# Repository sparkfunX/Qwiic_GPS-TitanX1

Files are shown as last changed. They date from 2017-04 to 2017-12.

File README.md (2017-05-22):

Qwiic GPS - Titan X1
========================================

Qwiic GPS with Titan X1

[*SPX-14312*](https://www.sparkfun.com/products/14312)

A breakboard board for the Titan X1 GPS module including an external antenna connection and RTC backup.

The [Qwiic system](http://www.sparkfun.com/qwiic) enables fast and solderless connection between popular platforms and various sensors and actuators. You can read more about the Qwiic system [here](http://www.sparkfun.com/qwiic). 

License Information
-------------------

This product is _**open source**_!

Please review the LICENSE.md file for license information.

If you have any questions or concerns on licensing, please contact techsupport@sparkfun.com.

Distributed as-is; no warranty is given.

- Your friends at SparkFun.

_<COLLABORATION CREDIT>_

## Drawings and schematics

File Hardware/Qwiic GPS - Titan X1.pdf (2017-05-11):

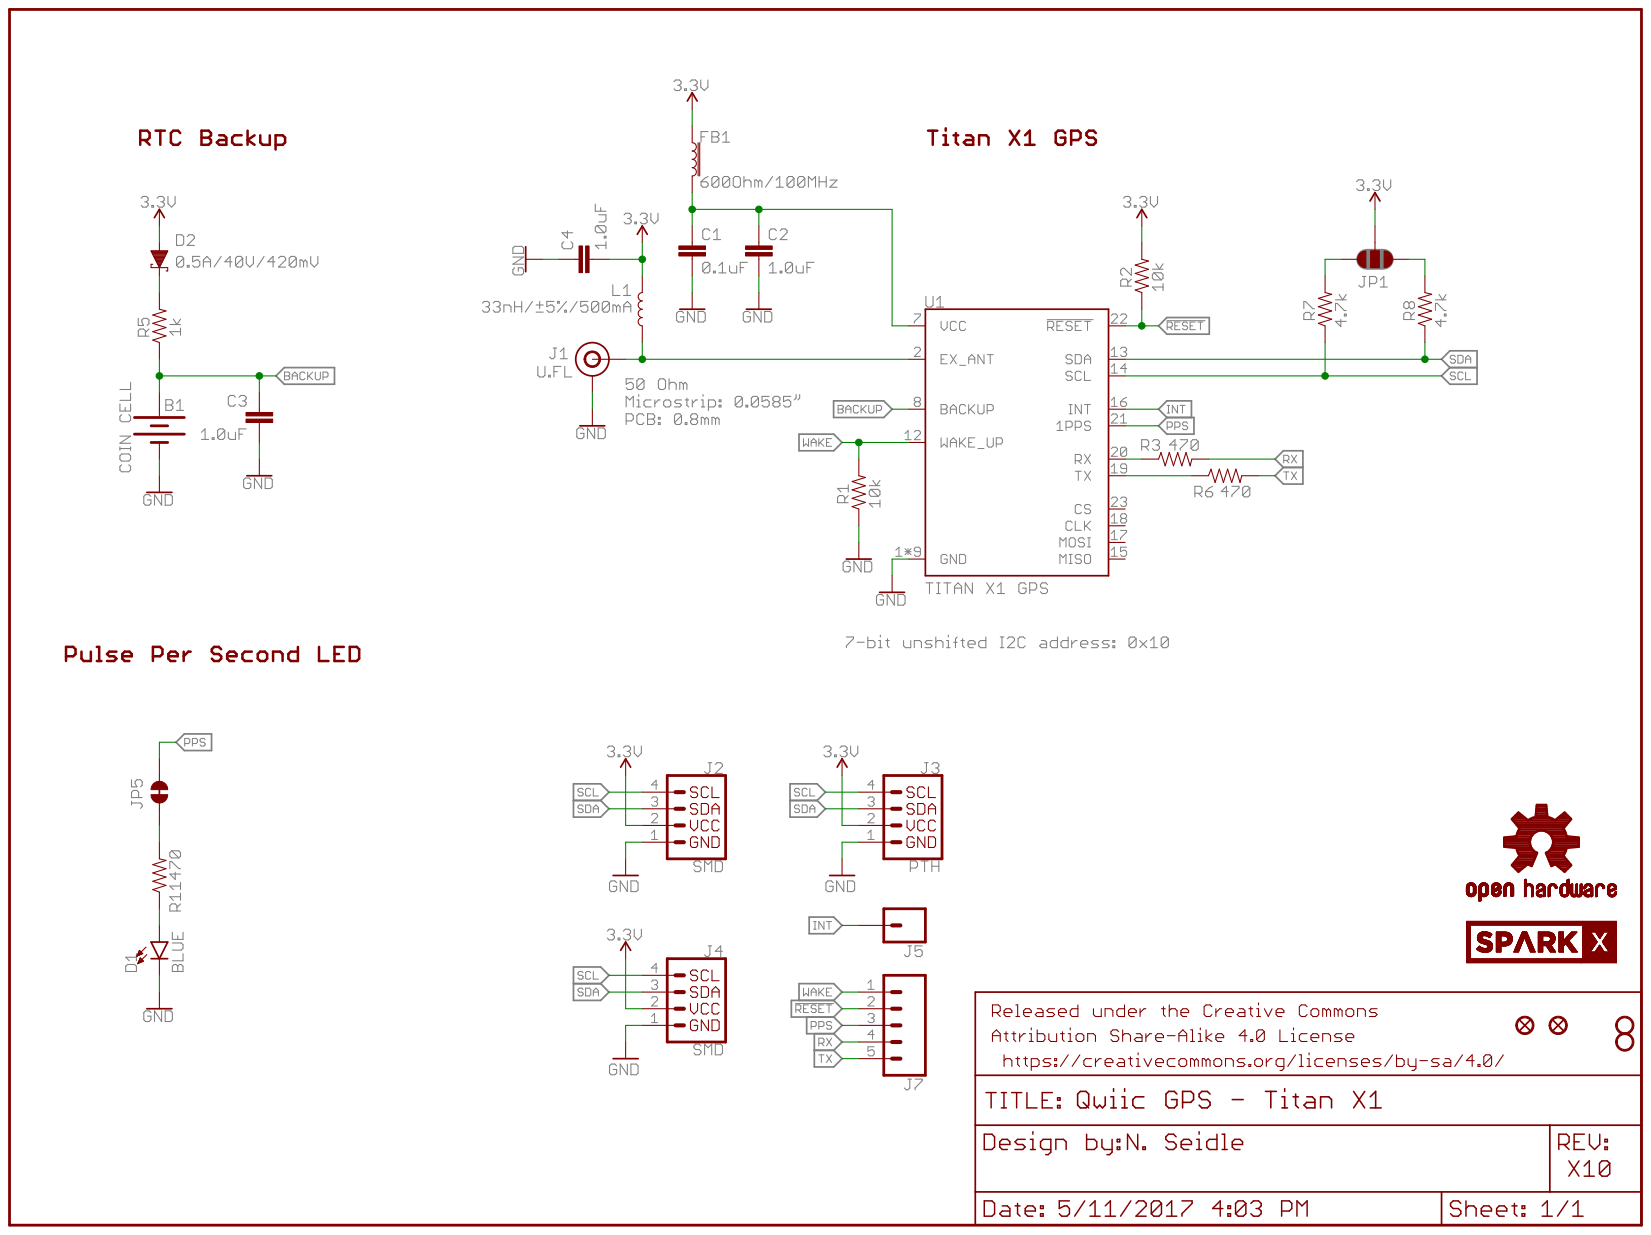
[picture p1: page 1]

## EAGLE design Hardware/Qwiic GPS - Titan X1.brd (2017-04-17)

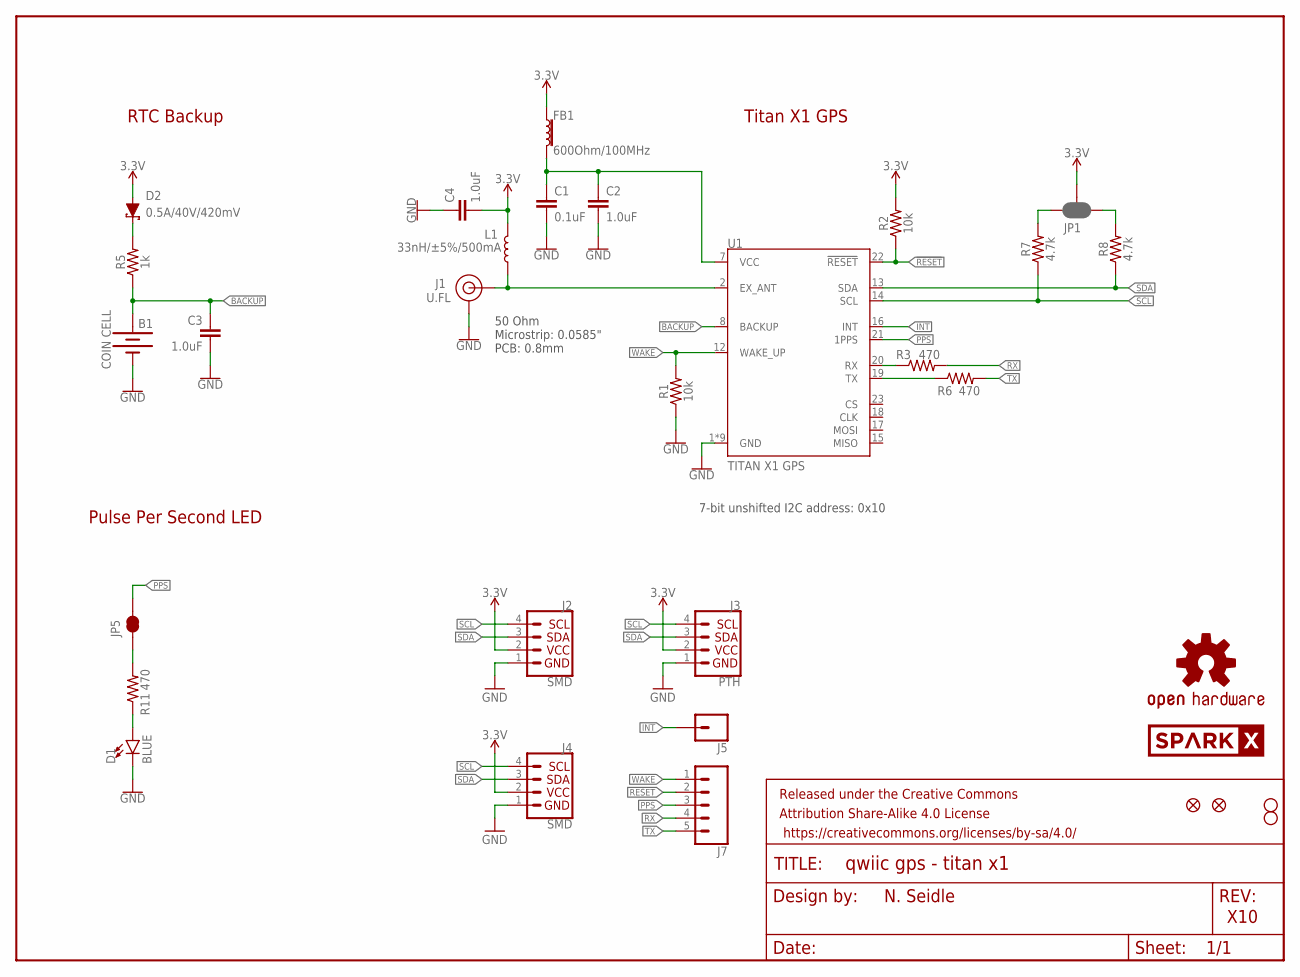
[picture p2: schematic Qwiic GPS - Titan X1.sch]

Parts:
B1: COIN CELL; 6.8MM_COIN_CELL
C1: 0.1uF; 0603
C2, C3, C4: 1.0uF; 0603
D1: BLUE; LED-0603
D2: 0.5A/40V/420mV; SOD-323
FB1: 600Ohm/100MHz; 0603
FRAME1: FRAME-LETTER; CREATIVE_COMMONS
J1: U.FL
J2, J4: SMD; 1X04_1MM_RA
J3: PTH; 1X04_NO_SILK
J5: CONN_01PTH_NO_SILK_YES_STOP; 1X01_NO_SILK
J7: CONN_05NO_SILK; 1X05_NO_SILK
JP1: JUMPER-SMT_3_2-NC_PASTE_SILK; SMT-JUMPER_3_2-NC_PASTE_SILK
JP2, JP6: FIDUCIALUFIDUCIAL; MICRO-FIDUCIAL
JP3, JP4: STAND-OFF
JP5: JUMPER-SMT_2_NC_TRACE_NO-SILK; SMT-JUMPER_2_NC_TRACE_NO-SILK
L1: 33nH/±5%/500mA; 0603
LOGO1: OSHW-LOGOMINI; OSHW-LOGO-MINI
R1, R2: 10k; 0603
R3, R6, R11: 470; 0603
R5: 1k; 0603
R7, R8: 4.7k; 0603
U1: TITAN X1 GPS; TITAN_X1_GPS
U$1: SPARKX-LOGO5; SPARKX-LARGE

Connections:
3.3V: C4.2, D2.A, FB1.1, J2.2 (VCC), J3.2 (VCC), J4.2 (VCC), JP1.2, L1.2, R2.2
!RESET: J7.2, R2.1, U1.22 (!RESET)
BACKUP: B1.+, C3.1, R5.1, U1.8 (BACKUP)
EXT_ANT: J1.FEED (SIGNAL), L1.1, U1.2 (EX_ANT)
GND: B1.-, C1.2, C2.2, C3.2, C4.1, D1.C, J1.1 (GND), J1.2 (GND), J2.1 (GND), J3.1 (GND), J4.1 (GND), R1.1, U1.1 (GND), U1.3 (GND), U1.4 (GND), U1.5 (GND), U1.6 (GND), U1.9 (GND), U1.10 (GND), U1.11 (GND), U1.24 (GND)
INT: J5.1, U1.16 (INT)
unnamed: D1.A, R11.1
unnamed: JP5.1, R11.2
unnamed: JP1.1, R8.2
unnamed: D2.C, R5.2
unnamed: JP1.3, R7.2
PPS: J7.3, JP5.2, U1.21 (1PPS)
RX: J7.4, R3.2
RXLV: R3.1, U1.20 (RX)
SCL: J2.4 (SCL), J3.4 (SCL), J4.4 (SCL), R7.1, U1.14 (SCL)
SDA: J2.3 (SDA), J3.3 (SDA), J4.3 (SDA), R8.1, U1.13 (SDA)
TX: J7.5, R6.2
TXLV: R6.1, U1.19 (TX)
VCC_FILTERED: C1.1, C2.1, FB1.2, U1.7 (VCC)
WAKE: J7.1, R1.2, U1.12 (WAKE_UP)

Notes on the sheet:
N. Seidle
X10
7-bit unshifted I2C address: 0x10
Titan X1 GPS
RTC Backup
Pulse Per Second LED
50 Ohm Microstrip: 0.0585" PCB: 0.8mm

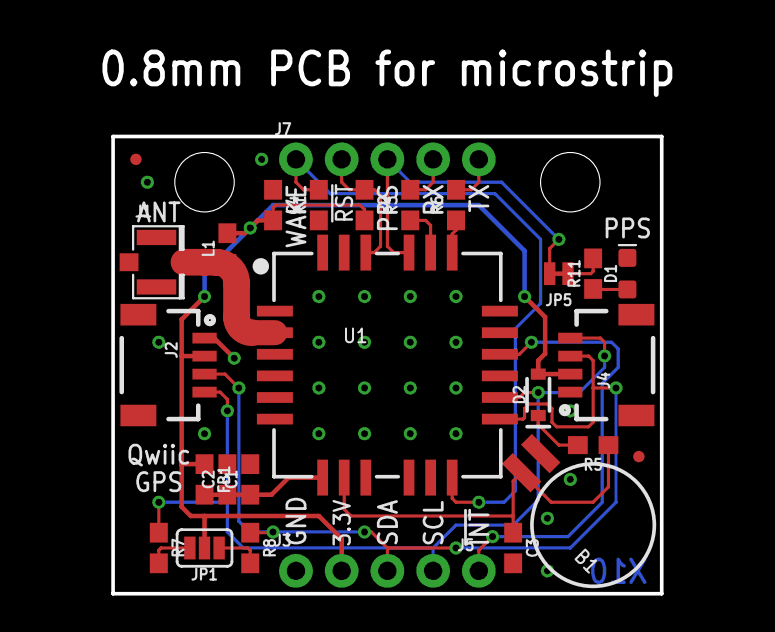
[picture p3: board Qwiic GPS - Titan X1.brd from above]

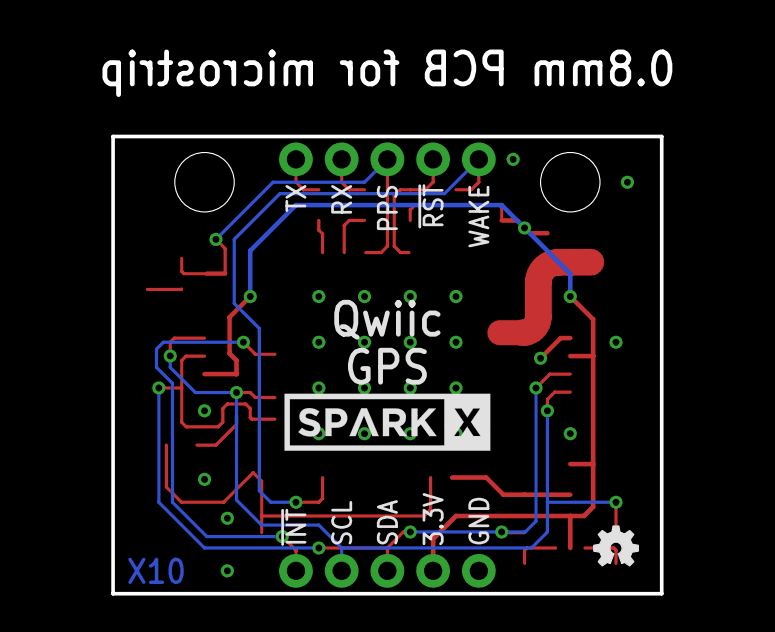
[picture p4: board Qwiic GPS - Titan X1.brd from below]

Board: 2 copper layers, 30.5 x 25.4 mm, 33 parts (2 on the bottom side), 20 nets.

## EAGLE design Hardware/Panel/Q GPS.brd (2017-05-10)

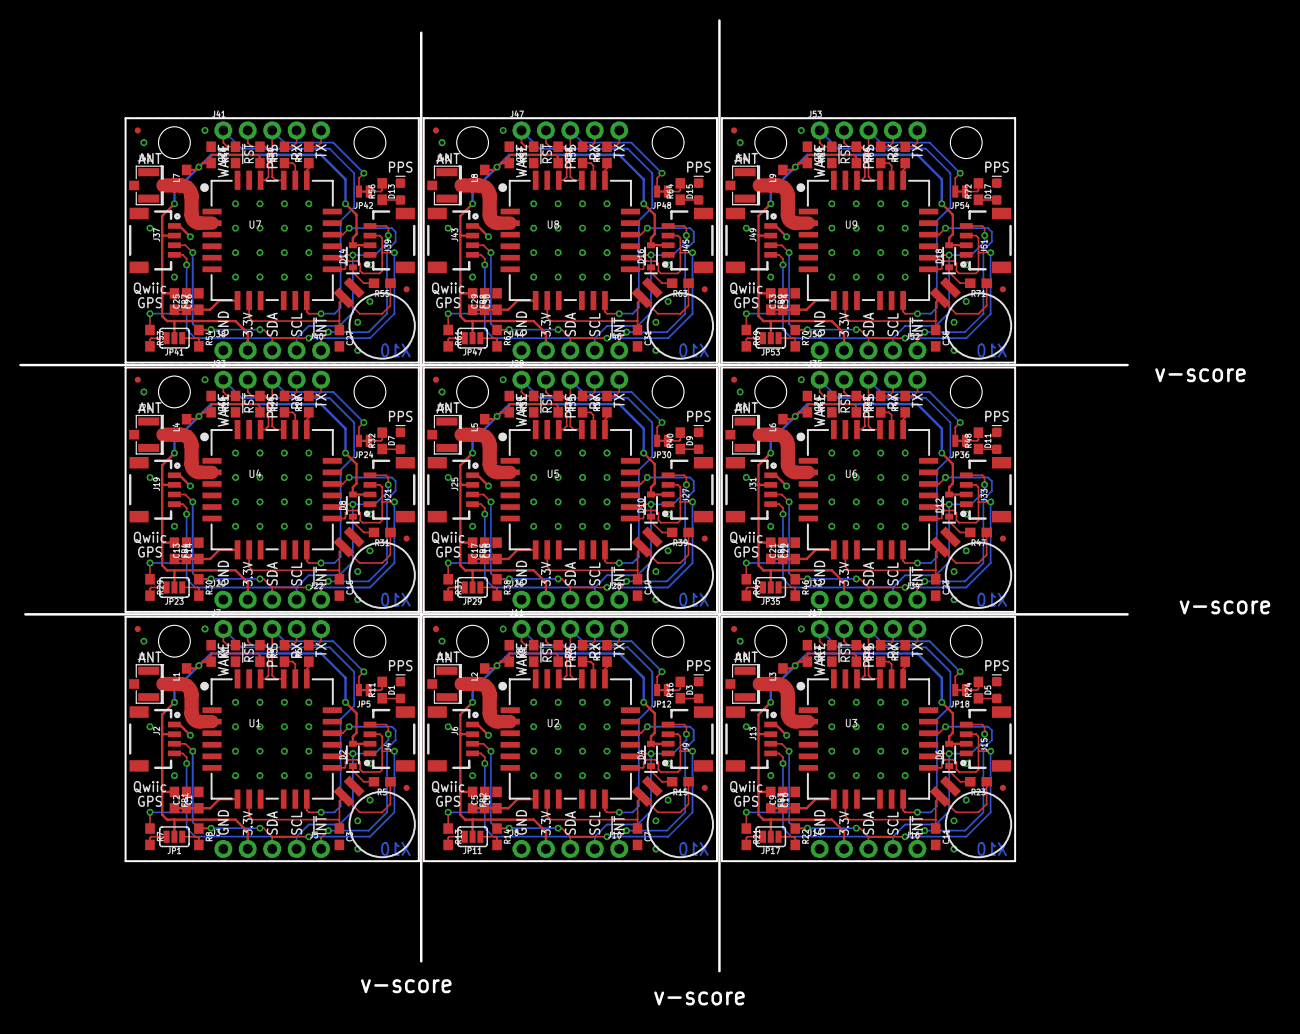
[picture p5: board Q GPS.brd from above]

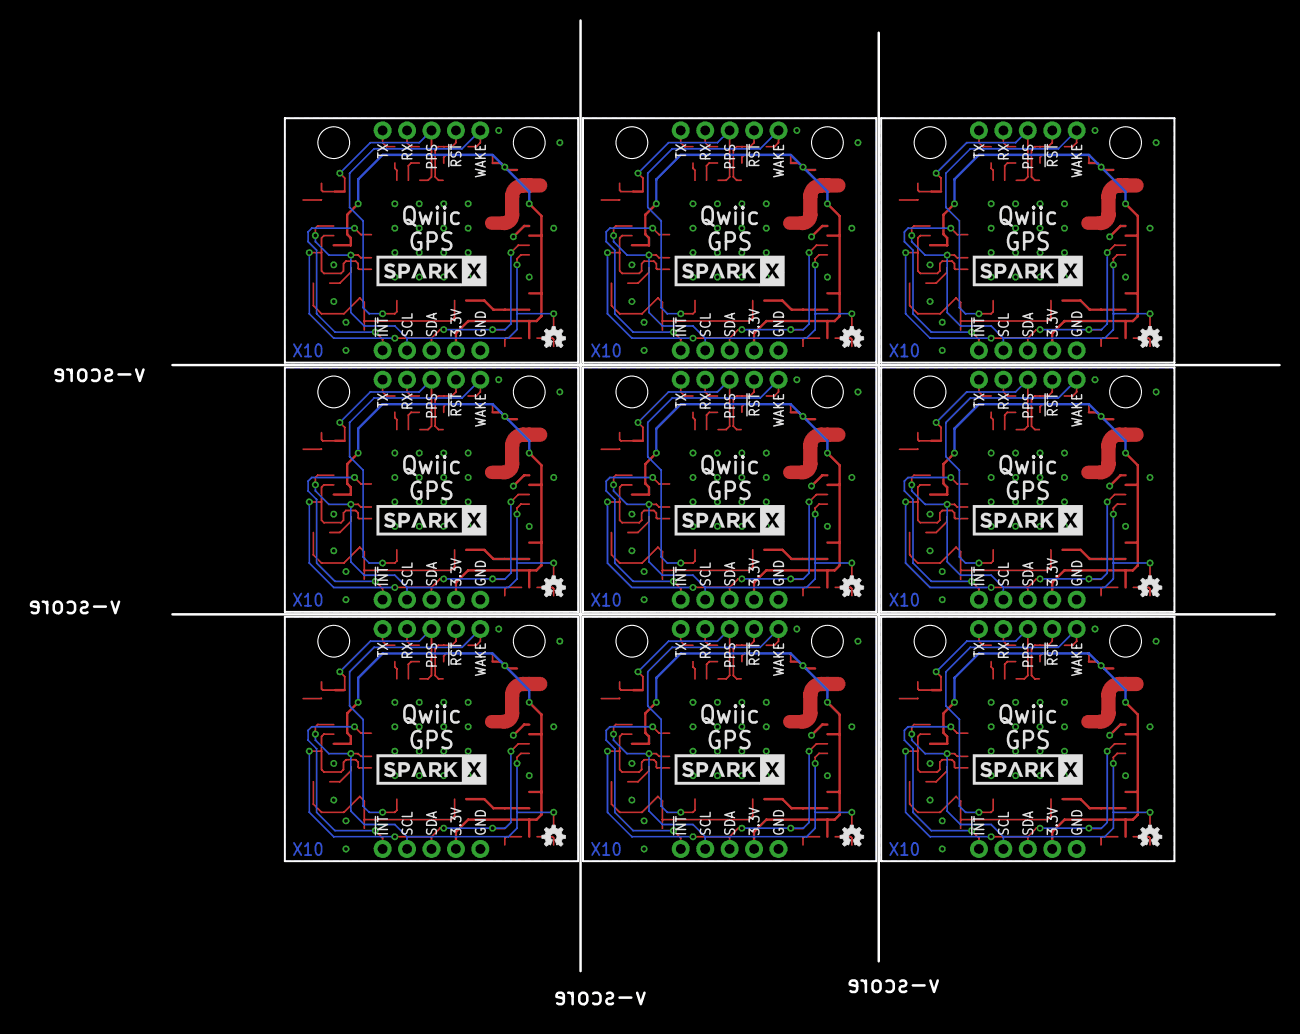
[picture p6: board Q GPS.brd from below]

Board: 2 copper layers, 115.1 x 98.8 mm, 288 parts (18 on the bottom side), 180 nets.

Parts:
B1, B2, B3, B4, B5, B6, B7, B8, B9: COIN CELL; 6.8MM_COIN_CELL
C1, C6, C10, C14, C18, C22, C26, C30, C34: 0.1uF; 0603
C2, C3, C4, C5, C7, C8, C9, C11, C12, C13, C15, C16, C17, C19, C20, C21, C23, C24, C25, C27, C28, C29, C31, C32, C33, C35, C36: 1.0uF; 0603
D1, D3, D5, D7, D9, D11, D13, D15, D17: BLUE; LED-0603
D2, D4, D6, D8, D10, D12, D14, D16, D18: 0.5A/40V/420mV; SOD-323
FB1, FB2, FB3, FB4, FB5, FB6, FB7, FB8, FB9: 600Ohm/100MHz; 0603
J1, J12, J18, J24, J30, J36, J42, J48, J54: U.FL
J2, J4, J6, J9, J13, J15, J19, J21, J25, J27, J31, J33, J37, J39, J43, J45, J49, J51: SMD; 1X04_1MM_RA
J3, J8, J14, J20, J26, J32, J38, J44, J50: PTH; 1X04_NO_SILK
J5, J10, J16, J22, J28, J34, J40, J46, J52: 1X01_NO_SILK
J7, J11, J17, J23, J29, J35, J41, J47, J53: 1X05_NO_SILK
JP1, JP11, JP17, JP23, JP29, JP35, JP41, JP47, JP53: SMT-JUMPER_3_2-NC_PASTE_SILK
JP2, JP6, JP9, JP10, JP15, JP16, JP21, JP22, JP27, JP28, JP33, JP34, JP39, JP40, JP45, JP46, JP51, JP52: FIDUCIALUFIDUCIAL; MICRO-FIDUCIAL
JP3, JP4, JP7, JP8, JP13, JP14, JP19, JP20, JP25, JP26, JP31, JP32, JP37, JP38, JP43, JP44, JP49, JP50: STAND-OFF
JP5, JP12, JP18, JP24, JP30, JP36, JP42, JP48, JP54: SMT-JUMPER_2_NC_TRACE_NO-SILK
L1, L2, L3, L4, L5, L6, L7, L8, L9: 33nH/±5%/500mA; 0603
LOGO1, LOGO2, LOGO3, LOGO4, LOGO5, LOGO6, LOGO7, LOGO8, LOGO9: OSHW-LOGOMINI; OSHW-LOGO-MINI
R1, R2, R4, R9, R17, R18, R25, R26, R33, R34, R41, R42, R49, R50, R57, R58, R65, R66: 10k; 0603
R3, R6, R10, R11, R12, R16, R19, R20, R24, R27, R28, R32, R35, R36, R40, R43, R44, R48, R51, R52, R56, R59, R60, R64, R67, R68, R72: 470; 0603
R5, R15, R23, R31, R39, R47, R55, R63, R71: 1k; 0603
R7, R8, R13, R14, R21, R22, R29, R30, R37, R38, R45, R46, R53, R54, R61, R62, R69, R70: 4.7k; 0603
U1, U2, U3, U4, U5, U6, U7, U8, U9: TITAN X1 GPS; TITAN_X1_GPS
U$1, U$2, U$3, U$4, U$5, U$6, U$7, U$8, U$9: SPARKX-LOGO5; SPARKX-LARGE

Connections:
1PPS: J7.3, JP5.2, U1.21
1PPS1: J11.3, JP12.2, U2.21
1PPS2: J17.3, JP18.2, U3.21
1PPS3: J23.3, JP24.2, U4.21
1PPS4: J29.3, JP30.2, U5.21
1PPS5: J35.3, JP36.2, U6.21
1PPS6: J41.3, JP42.2, U7.21
1PPS7: J47.3, JP48.2, U8.21
1PPS8: J53.3, JP54.2, U9.21
3.3V: C4.2, D2.A, FB1.1, J2.2, J3.2, J4.2, JP1.2, L1.2, R2.2
3.3V1: C8.2, D4.A, FB2.1, J6.2, J8.2, J9.2, JP11.2, L2.2, R9.2
3.3V2: C12.2, D6.A, FB3.1, J13.2, J14.2, J15.2, JP17.2, L3.2, R18.2
3.3V3: C16.2, D8.A, FB4.1, J19.2, J20.2, J21.2, JP23.2, L4.2, R26.2
3.3V4: C20.2, D10.A, FB5.1, J25.2, J26.2, J27.2, JP29.2, L5.2, R34.2
3.3V5: C24.2, D12.A, FB6.1, J31.2, J32.2, J33.2, JP35.2, L6.2, R42.2
3.3V6: C28.2, D14.A, FB7.1, J37.2, J38.2, J39.2, JP41.2, L7.2, R50.2
3.3V7: C32.2, D16.A, FB8.1, J43.2, J44.2, J45.2, JP47.2, L8.2, R58.2
3.3V8: C36.2, D18.A, FB9.1, J49.2, J50.2, J51.2, JP53.2, L9.2, R66.2
!RESET: J7.2, R2.1, U1.22
!RESET1: J11.2, R9.1, U2.22
!RESET2: J17.2, R18.1, U3.22
!RESET3: J23.2, R26.1, U4.22
!RESET4: J29.2, R34.1, U5.22
!RESET5: J35.2, R42.1, U6.22
!RESET6: J41.2, R50.1, U7.22
!RESET7: J47.2, R58.1, U8.22
!RESET8: J53.2, R66.1, U9.22
BACKUP: B1.+, C3.1, R5.1, U1.8
BACKUP1: B2.+, C7.1, R15.1, U2.8
BACKUP2: B3.+, C11.1, R23.1, U3.8
BACKUP3: B4.+, C15.1, R31.1, U4.8
BACKUP4: B5.+, C19.1, R39.1, U5.8
BACKUP5: B6.+, C23.1, R47.1, U6.8
BACKUP6: B7.+, C27.1, R55.1, U7.8
BACKUP7: B8.+, C31.1, R63.1, U8.8
BACKUP8: B9.+, C35.1, R71.1, U9.8
EXT_ANT: J1.FEED, L1.1, U1.2
EXT_ANT1: J12.FEED, L2.1, U2.2
EXT_ANT2: J18.FEED, L3.1, U3.2
EXT_ANT3: J24.FEED, L4.1, U4.2
EXT_ANT4: J30.FEED, L5.1, U5.2
EXT_ANT5: J36.FEED, L6.1, U6.2
EXT_ANT6: J42.FEED, L7.1, U7.2
EXT_ANT7: J48.FEED, L8.1, U8.2
EXT_ANT8: J54.FEED, L9.1, U9.2
GND: B1.-, C1.2, C2.2, C3.2, C4.1, D1.C, J1.1, J1.2, J2.1, J3.1, J4.1, R1.1, U1.1, U1.3, U1.4, U1.5, U1.6, U1.9, U1.10, U1.11, U1.24
GND1: B2.-, C5.2, C6.2, C7.2, C8.1, D3.C, J6.1, J8.1, J9.1, J12.1, J12.2, R4.1, U2.1, U2.3, U2.4, U2.5, U2.6, U2.9, U2.10, U2.11, U2.24
GND2: B3.-, C9.2, C10.2, C11.2, C12.1, D5.C, J13.1, J14.1, J15.1, J18.1, J18.2, R17.1, U3.1, U3.3, U3.4, U3.5, U3.6, U3.9, U3.10, U3.11, U3.24
GND3: B4.-, C13.2, C14.2, C15.2, C16.1, D7.C, J19.1, J20.1, J21.1, J24.1, J24.2, R25.1, U4.1, U4.3, U4.4, U4.5, U4.6, U4.9, U4.10, U4.11, U4.24
GND4: B5.-, C17.2, C18.2, C19.2, C20.1, D9.C, J25.1, J26.1, J27.1, J30.1, J30.2, R33.1, U5.1, U5.3, U5.4, U5.5, U5.6, U5.9, U5.10, U5.11, U5.24
GND5: B6.-, C21.2, C22.2, C23.2, C24.1, D11.C, J31.1, J32.1, J33.1, J36.1, J36.2, R41.1, U6.1, U6.3, U6.4, U6.5, U6.6, U6.9, U6.10, U6.11, U6.24
GND6: B7.-, C25.2, C26.2, C27.2, C28.1, D13.C, J37.1, J38.1, J39.1, J42.1, J42.2, R49.1, U7.1, U7.3, U7.4, U7.5, U7.6, U7.9, U7.10, U7.11, U7.24
GND7: B8.-, C29.2, C30.2, C31.2, C32.1, D15.C, J43.1, J44.1, J45.1, J48.1, J48.2, R57.1, U8.1, U8.3, U8.4, U8.5, U8.6, U8.9, U8.10, U8.11, U8.24
GND8: B9.-, C33.2, C34.2, C35.2, C36.1, D17.C, J49.1, J50.1, J51.1, J54.1, J54.2, R65.1, U9.1, U9.3, U9.4, U9.5, U9.6, U9.9, U9.10, U9.11, U9.24
INT: J5.1, U1.16
INT1: J10.1, U2.16
INT2: J16.1, U3.16
INT3: J22.1, U4.16
INT4: J28.1, U5.16
INT5: J34.1, U6.16
INT6: J40.1, U7.16
INT7: J46.1, U8.16
INT8: J52.1, U9.16
unnamed: JP11.1, R14.2
unnamed: D1.A, R11.1
unnamed: JP11.3, R13.2
unnamed: JP5.1, R11.2
unnamed: JP1.1, R8.2
unnamed: D2.C, R5.2
unnamed: D3.A, R16.1
unnamed: JP1.3, R7.2
unnamed: JP12.1, R16.2
unnamed: D4.C, R15.2
unnamed: JP17.1, R22.2
unnamed: JP17.3, R21.2
unnamed: D5.A, R24.1
unnamed: JP18.1, R24.2
unnamed: D6.C, R23.2
unnamed: JP23.1, R30.2
unnamed: JP23.3, R29.2
unnamed: D7.A, R32.1
unnamed: JP24.1, R32.2
unnamed: D8.C, R31.2
unnamed: JP29.1, R38.2
unnamed: JP29.3, R37.2
unnamed: D9.A, R40.1
unnamed: JP30.1, R40.2
unnamed: D10.C, R39.2
unnamed: JP35.1, R46.2
unnamed: JP35.3, R45.2
unnamed: D11.A, R48.1
unnamed: JP36.1, R48.2
unnamed: D12.C, R47.2
unnamed: JP41.1, R54.2
unnamed: JP41.3, R53.2
unnamed: D13.A, R56.1
unnamed: JP42.1, R56.2
unnamed: D14.C, R55.2
unnamed: JP47.1, R62.2
unnamed: JP47.3, R61.2
unnamed: D15.A, R64.1
unnamed: JP48.1, R64.2
unnamed: D16.C, R63.2
unnamed: JP53.1, R70.2
unnamed: JP53.3, R69.2
unnamed: D17.A, R72.1
unnamed: JP54.1, R72.2
unnamed: D18.C, R71.2
RX: J7.4, R3.2
RX1: J11.4, R10.2
RX2: J17.4, R19.2
RX3: J23.4, R27.2
RX4: J29.4, R35.2
RX5: J35.4, R43.2
RX6: J41.4, R51.2
RX7: J47.4, R59.2
RX8: J53.4, R67.2
RXLV: R3.1, U1.20
RXLV1: R10.1, U2.20
RXLV2: R19.1, U3.20
RXLV3: R27.1, U4.20
RXLV4: R35.1, U5.20
RXLV5: R43.1, U6.20
RXLV6: R51.1, U7.20
RXLV7: R59.1, U8.20
RXLV8: R67.1, U9.20
SCL: J2.4, J3.4, J4.4, R7.1, U1.14
SCL1: J6.4, J8.4, J9.4, R13.1, U2.14
SCL2: J13.4, J14.4, J15.4, R21.1, U3.14
SCL3: J19.4, J20.4, J21.4, R29.1, U4.14
SCL4: J25.4, J26.4, J27.4, R37.1, U5.14
SCL5: J31.4, J32.4, J33.4, R45.1, U6.14
SCL6: J37.4, J38.4, J39.4, R53.1, U7.14
SCL7: J43.4, J44.4, J45.4, R61.1, U8.14
SCL8: J49.4, J50.4, J51.4, R69.1, U9.14
SDA: J2.3, J3.3, J4.3, R8.1, U1.13
SDA1: J6.3, J8.3, J9.3, R14.1, U2.13
SDA2: J13.3, J14.3, J15.3, R22.1, U3.13
SDA3: J19.3, J20.3, J21.3, R30.1, U4.13
SDA4: J25.3, J26.3, J27.3, R38.1, U5.13
SDA5: J31.3, J32.3, J33.3, R46.1, U6.13
SDA6: J37.3, J38.3, J39.3, R54.1, U7.13
SDA7: J43.3, J44.3, J45.3, R62.1, U8.13
SDA8: J49.3, J50.3, J51.3, R70.1, U9.13
TX: J7.5, R6.2
TX1: J11.5, R12.2
TX2: J17.5, R20.2
TX3: J23.5, R28.2
TX4: J29.5, R36.2
TX5: J35.5, R44.2
TX6: J41.5, R52.2
TX7: J47.5, R60.2
TX8: J53.5, R68.2
TXLV: R6.1, U1.19
TXLV1: R12.1, U2.19
TXLV2: R20.1, U3.19
TXLV3: R28.1, U4.19
TXLV4: R36.1, U5.19
TXLV5: R44.1, U6.19
TXLV6: R52.1, U7.19
TXLV7: R60.1, U8.19
TXLV8: R68.1, U9.19
VCC_FILTERED: C1.1, C2.1, FB1.2, U1.7
VCC_FILTERED1: C5.1, C6.1, FB2.2, U2.7
VCC_FILTERED2: C9.1, C10.1, FB3.2, U3.7
VCC_FILTERED3: C13.1, C14.1, FB4.2, U4.7
VCC_FILTERED4: C17.1, C18.1, FB5.2, U5.7
VCC_FILTERED5: C21.1, C22.1, FB6.2, U6.7
VCC_FILTERED6: C25.1, C26.1, FB7.2, U7.7
VCC_FILTERED7: C29.1, C30.1, FB8.2, U8.7
VCC_FILTERED8: C33.1, C34.1, FB9.2, U9.7
WAKE: J7.1, R1.2, U1.12
WAKE1: J11.1, R4.2, U2.12
WAKE2: J17.1, R17.2, U3.12
WAKE3: J23.1, R25.2, U4.12
WAKE4: J29.1, R33.2, U5.12
WAKE5: J35.1, R41.2, U6.12
WAKE6: J41.1, R49.2, U7.12
WAKE7: J47.1, R57.2, U8.12
WAKE8: J53.1, R65.2, U9.12

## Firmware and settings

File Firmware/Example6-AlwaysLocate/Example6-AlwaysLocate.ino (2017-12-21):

/*
  Configure GPS module for low power operate
  By: Nathan Seidle
  SparkFun Electronics
  Date: April 12th, 2017
  License: This code is public domain but you buy me a beer if you use this and we meet someday (Beerware license).

  This example shows how to configure the module including:
    AlwaysLocate (packet # 225)

  For more information see the MTK NMEA Packet datasheet.

  Note that these settings are stored in battery backed memory and will be retained for
  approximately 16 days without power.

  Hardware Connections:
  Attach a Qwiic shield to your RedBoard or Uno.
  Plug the Qwiic sensor into any port.
  Serial.print it out at 115200 baud to serial monitor.
*/

#include <SparkFun_I2C_GPS_Arduino_Library.h> //Use Library Manager or download here: https://github.com/sparkfun/SparkFun_I2C_GPS_Arduino_Library
I2CGPS myI2CGPS; //Hook object to the library

#include <TinyGPS++.h> //From: https://github.com/mikalhart/TinyGPSPlus
TinyGPSPlus gps; //Declare gps object

//The following tells the TinyGPS library to scan for the PMTK001 sentence
//This sentence is the response to a configure command from the user
//Field 1 is the packet number, 2 indicates if configuration was successful
TinyGPSCustom configureCmd(gps, "PMTK001", 1); //Packet number
TinyGPSCustom configureFlag(gps, "PMTK001", 2); //Success/fail flag

String configString;

boolean debug = false; //Keeps track of the enable/disable of debug printing within the GPS lib

void setup()
{
  Serial.begin(115200);
  Serial.println("GPS Configuration Example");

  if (myI2CGPS.begin() == false)
  {
    Serial.println("Module failed to respond. Please check wiring.");
    while (1); //Freeze!
  }
  Serial.println("GPS module found!");

  //myI2CGPS.enableDebugging(); //Turn on printing of GPS strings
  myI2CGPS.disableDebugging(); //Turn off printing of GPS strings
  debug = false;

  printMenu();
}

void loop()
{
  if (Serial.available())
  {
    byte incoming = Serial.read();
    if (incoming == '1')
    {
      //Packet 220: Set time between fixes (update rate)
      //Milliseconds between output. 100 to 10,000 is allowed.
      //Example 1 Hz: ",1000"
      //Example 2 Hz: ",500"
      //Example 10 Hz: ",100"
      //NOTE: You must increase the baud rate to 57600bps or higher to reach 10Hz
      configString = myI2CGPS.createMTKpacket(220, ",100");
      myI2CGPS.sendMTKpacket(configString);

      Serial.println(F("You must increase the baud rate to 57600bps or higher to reach 10Hz"));
    }
    else if (incoming == '2')
    {
      //Packet 225: Enter Standby or Backup mode for power saving
      //PMTK255, Type, Run time, Sleep time, Second run time, Second sleep time
      //6 types of modes
      
      configString = myI2CGPS.createMTKpacket(225, ",0"); //Go to normal mode
      myI2CGPS.sendMTKpacket(configString);
    }
    else if (incoming == '3')
    {
      //Packet 225: Enter Standby or Backup mode for power saving
      //PMTK255, Type, Run time, Sleep time, Second run time, Second sleep time
      //6 types of modes
      
      configString = myI2CGPS.createMTKpacket(225, ",0"); //Go to normal mode
      myI2CGPS.sendMTKpacket(configString);

      delay(1000);
      
      configString = myI2CGPS.createMTKpacket(223, ",1,25,180000,60000"); //Recommended to be used with 225
      myI2CGPS.sendMTKpacket(configString);

      delay(1000);
      
      configString = myI2CGPS.createMTKpacket(225, ",1,3000,12000,18000,72000"); //Periodic backup mode, 3s to fix, 12s sleep, 18s fix, 72s sleep
      myI2CGPS.sendMTKpacket(configString);
    }
    else if (incoming == '4')
    {
      //Packet 225: Enter Standby or Backup mode for power saving
      //PMTK255, Type, Run time, Sleep time, Second run time, Second sleep time
      //6 types of modes
      
      configString = myI2CGPS.createMTKpacket(225, ",0"); //Go to normal mode
      myI2CGPS.sendMTKpacket(configString);

      delay(1000);
      
      configString = myI2CGPS.createMTKpacket(225, ",9"); //Periodic AlwaysLocate backup mode
      myI2CGPS.sendMTKpacket(configString);
    }

    else if (incoming == '9')
    {
      //Packet 104: Reset to factory defaults
      //Erases all system and user configurations. Does cold start.
      //Note: Unit does not respond with an ACK packet
      //Note: If you're using an external anteanna you must power cycle the module
      //so that it detects the external antenna
      configString = myI2CGPS.createMTKpacket(104, "");
      myI2CGPS.sendMTKpacket(configString);

      Serial.println(F("Reset command sent. No ACK is returned for this command."));
    }
    else
    {
      printMenu();
    }
  }

  while (myI2CGPS.available()) //available() returns the number of new bytes available from the GPS module
  {
    gps.encode(myI2CGPS.read()); //Feed the GPS parser with a new .read() byte
  }

  if (gps.time.isUpdated()) //Check to see if new GPS info is available
  {
    displayInfo();
  }

  //Check to see if we got a response from any command we recently sent
  if (configureCmd.isUpdated())
  {
    Serial.print("Packet ");
    Serial.print(configureCmd.value());
    Serial.print(": ");

    switch (configureFlag.value()[0])
    {
      case '0':
        Serial.print(F("Invalid command"));
        break;
      case '1':
        Serial.print(F("Unsupported command"));
        break;
      case '2':
        Serial.print(F("Action failed"));
        break;
      case '3':
        Serial.print(F("Command successful"));
        break;
    }

    Serial.println();
  }

  delay(10);
}

void printMenu(void)
{
  Serial.println();
  Serial.println(F("1) Set update rate to 10Hz"));
  Serial.println(F("2) Go to normal mode"));
  Serial.println(F("3) Go to periodic backup mode"));
  Serial.println(F("4) Go to AlwaysLocate backup mode"));
  Serial.println(F("9) Reset module"));
}

void displayInfo()
{
  //We have new GPS data to deal with!

  if (gps.time.hour() < 10) Serial.print(F("0"));
  Serial.print(gps.time.hour());
  Serial.print(F(":"));
  if (gps.time.minute() < 10) Serial.print(F("0"));
  Serial.print(gps.time.minute());
  Serial.print(F(":"));
  if (gps.time.second() < 10) Serial.print(F("0"));
  Serial.print(gps.time.second());

  if (gps.location.isValid())
  {
    Serial.print(" Loc:");
    Serial.print(gps.location.lat(), 6);
    Serial.print(F(","));
    Serial.print(gps.location.lng(), 6);

    Serial.print(F(" SIV:"));
    Serial.print(gps.satellites.value());

    Serial.print(F(" HDOP:"));
    Serial.print(gps.hdop.value());
  }

  Serial.println();
}

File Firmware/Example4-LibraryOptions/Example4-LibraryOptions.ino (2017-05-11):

/*
  Reading Lat/Long from the Qwiic GPS module over I2C
  By: Nathan Seidle
  SparkFun Electronics
  Date: April 12th, 2017
  License: This code is public domain but you buy me a beer if you use this and we meet someday (Beerware license).

  This example shows how to run library at 400kHz and on different Wire ports (like Teensy).

  Some platforms have multiple Wire ports. The library accepts these in .begin(). For example:
  myI2CGPS.begin(Wire2, 400000) will tell libaray to communicate over Wire2 port at 400kHz fast I2C
  
  Hardware Connections:
  Attach a Qwiic shield to your RedBoard or Uno.
  Plug the Qwiic sensor into any port.
  Serial.print it out at 115200 baud to serial monitor.
*/

#include <SparkFun_I2C_GPS_Arduino_Library.h> //Use Library Manager or download here: https://github.com/sparkfun/SparkFun_I2C_GPS_Arduino_Library
I2CGPS myI2CGPS; //Hook object to the library

#include <TinyGPS++.h> //From: https://github.com/mikalhart/TinyGPSPlus
TinyGPSPlus gps; //Declare gps object

void setup()
{
  Serial.begin(115200);
  Serial.println("GPS Read Example");

  //Use Wire as our I2C port. Wire1, Wire2, etc are allowed. Wire is default.
  //Use fast 400kHz I2C. 100kHz is default
  if (myI2CGPS.begin(Wire, 400000) == false)
  {
    Serial.println("Module failed to respond. Please check wiring.");
    while (1); //Freeze!
  }
  Serial.println("GPS module found!");

  myI2CGPS.enableDebugging(Serial); //Turn on printing of GPS strings over the Serial port. SerialUSB, etc are allowed
  //But you must do a SerialUSB.begin(9600) or whatever in this function. Library cannot do .begin() for Streams.

  //myI2CGPS.disableDebugging(); //Turn off printing of GPS strings
}

void loop()
{
  while (myI2CGPS.available()) //available() returns the number of new bytes available from the GPS module
  {
    gps.encode(myI2CGPS.read()); //Feed the GPS parser
  }

  if (gps.time.isUpdated()) //Check to see if new GPS info is available
  {
    displayInfo();
  }
}

void displayInfo()
{
  //We have new GPS data to deal with!
  Serial.println();

  if (gps.time.isValid())
  {
    Serial.print(F("Date: "));
    Serial.print(gps.date.month());
    Serial.print(F("/"));
    Serial.print(gps.date.day());
    Serial.print(F("/"));
    Serial.print(gps.date.year());

    Serial.print((" Time: "));
    if (gps.time.hour() < 10) Serial.print(F("0"));
    Serial.print(gps.time.hour());
    Serial.print(F(":"));
    if (gps.time.minute() < 10) Serial.print(F("0"));
    Serial.print(gps.time.minute());
    Serial.print(F(":"));
    if (gps.time.second() < 10) Serial.print(F("0"));
    Serial.print(gps.time.second());

    Serial.println(); //Done printing time
  }
  else
  {
    Serial.println(F("Time not yet valid"));
  }

  if (gps.location.isValid())
  {
    Serial.print("Location: ");
    Serial.print(gps.location.lat(), 6);
    Serial.print(F(", "));
    Serial.print(gps.location.lng(), 6);
    Serial.println();
  }
  else
  {
    Serial.println(F("Location not yet valid"));
  }

  if (gps.altitude.isValid())
  {
    Serial.print(F("Altitude Meters:"));
    Serial.print(gps.altitude.meters());
    Serial.print(F(" Feet:"));
    Serial.print(gps.altitude.feet());
  }

  if (gps.satellites.isValid())
  {
    Serial.print(F(" Satellites in View:"));
    Serial.print(gps.satellites.value());
  }

  if (gps.hdop.isValid())
  {
    Serial.print(F(" HDOP:"));
    Serial.print(gps.hdop.value());
  }

  Serial.println(); //Done printing alt, siv, hdop
}

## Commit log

2017-03-23 Initial Commit - Millable Version
    [Millable_TitanX1_GPS_Breakout.GBL, Millable_TitanX1_GPS_Breakout.GBO, Millable_TitanX1_GPS_Breakout.GBS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]
2017-03-31 Adding programming document
    [Millable_TitanX1_GPS_Breakout.brd]
2017-04-17 Adding example firmware, docs, and Qwiic board.
    [Millable_TitanX1_GPS_Breakout.brd, Millable_TitanX1_GPS_Breakout.sch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]
2017-05-10 Commit before converting examples to library.
    Contains working examples that don't use the library. Soon to be
    changed.
    [Q GPS.brd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]
2017-05-11 Renaming files
    [Millable_TitanX1_GPS_Breakout.GBL, Millable_TitanX1_GPS_Breakout.GBO, Millable_TitanX1_GPS_Breakout.GBS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]

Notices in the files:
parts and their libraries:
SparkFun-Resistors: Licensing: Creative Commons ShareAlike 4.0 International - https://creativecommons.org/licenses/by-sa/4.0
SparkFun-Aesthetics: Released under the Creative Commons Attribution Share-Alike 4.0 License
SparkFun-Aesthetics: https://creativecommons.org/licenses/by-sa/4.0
